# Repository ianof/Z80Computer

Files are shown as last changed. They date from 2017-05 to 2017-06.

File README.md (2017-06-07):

# Z80 Toggle-Switch Computer
A minimalistic computer using the Zilog Z80 microprocessor as an educational display.

The computer will be operated using the following controls:

  * 8 toggle-switches to specify an address in the RAM
  * 8 toggle-switches to enter data into the RAM
  * 8 LEDs to display the address bus
  * 8 LEDs to display the data bus
  * A potentiometer to control the clock speed
  * A toggle-switch to switch between running and writing to the RAM
  * A toggle-switch to switch between running continuously and single-stepping instructions
  * A button to step instructions
  * A button to read from the RAM
  * A button to write to the RAM

The computer will be in a laser-cut plywood housing. SolidWorks files for this can be found in the "Housing" folder.

A printed circuit board contains all the circuitry for the computer. Gerber files for this can be found in the "PCBFiles" folder. A schematic can be found in the "KiCad" folder.

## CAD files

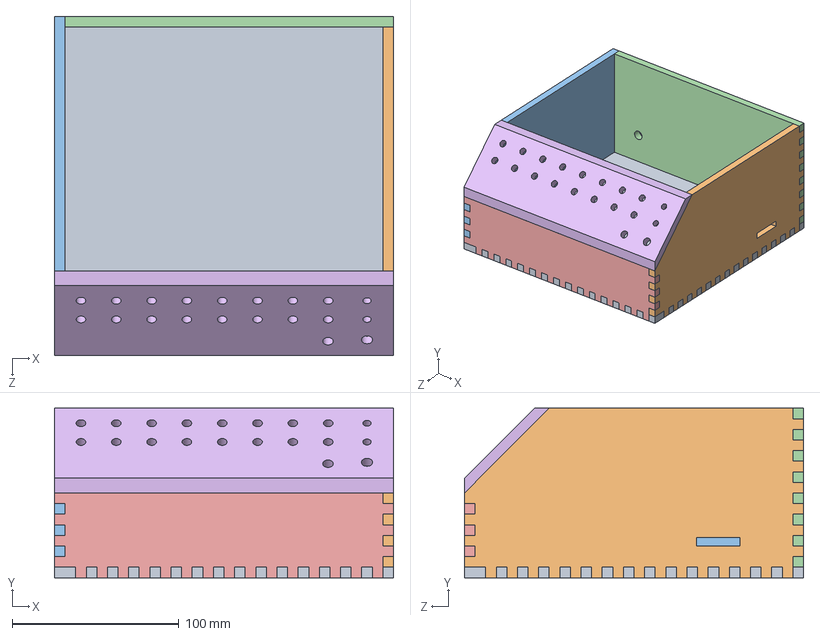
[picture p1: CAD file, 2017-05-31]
Housing/Z80 Box_assembly.SLDASM
203.2 x 101.6 x 203.2 mm
Z80 Box_base
Z80 Box_side_right
Z80 Box_side_left
Z80 Box_back
Z80 Box_front_bottom
Z80 Box_front_top

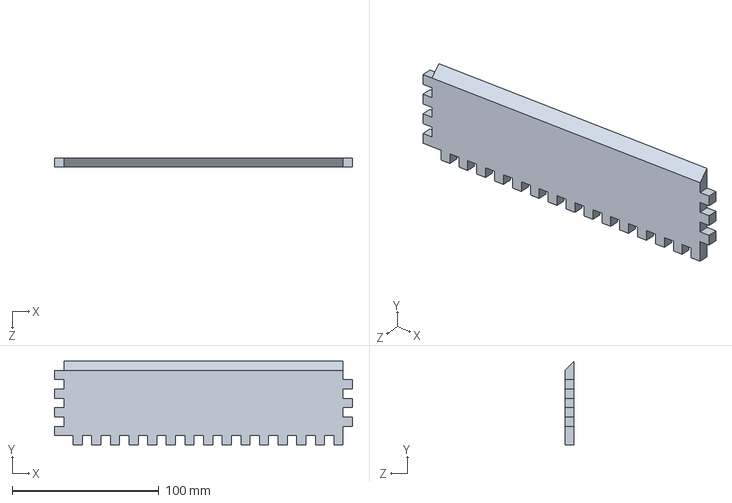
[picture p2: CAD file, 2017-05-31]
Housing/Z80 Box_front_bottom.SLDPRT
203.2 x 57.1 x 6.35 mm

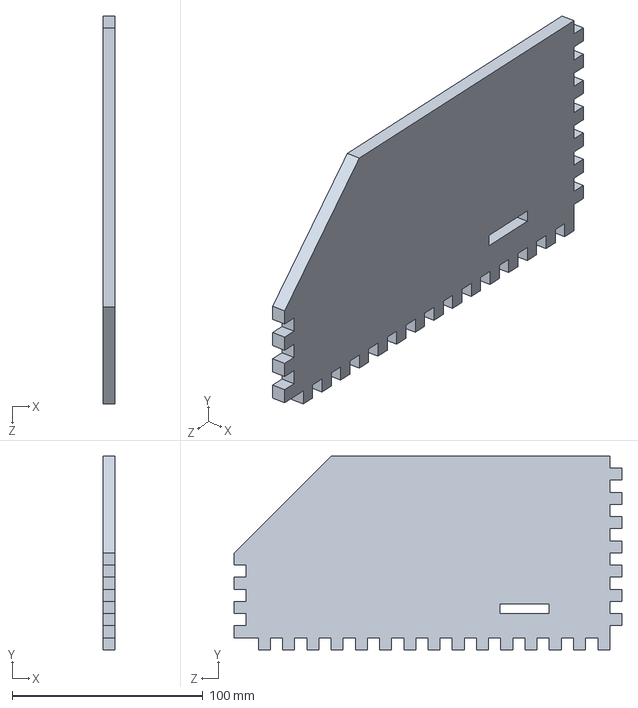
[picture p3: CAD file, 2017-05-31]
Housing/Z80 Box_side_right.SLDPRT
6.35 x 101.6 x 203.2 mm

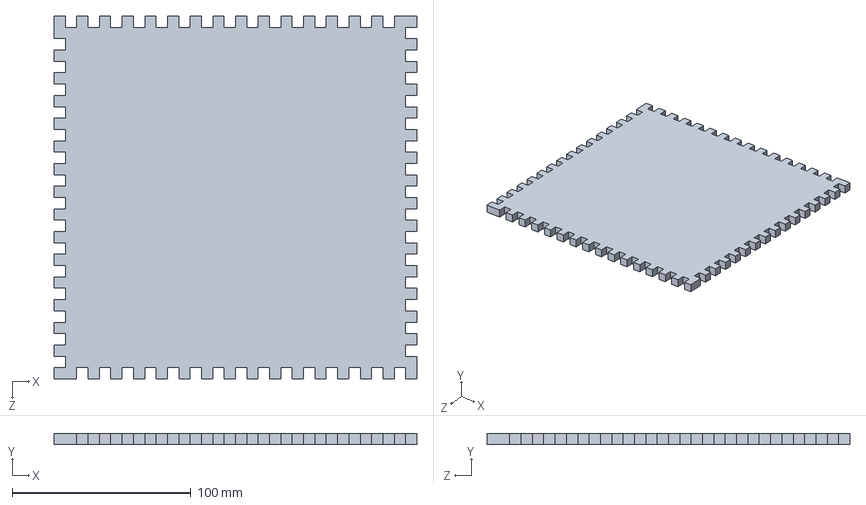
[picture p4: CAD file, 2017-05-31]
Housing/Z80 Box_base.SLDPRT
203.2 x 6.35 x 203.2 mm

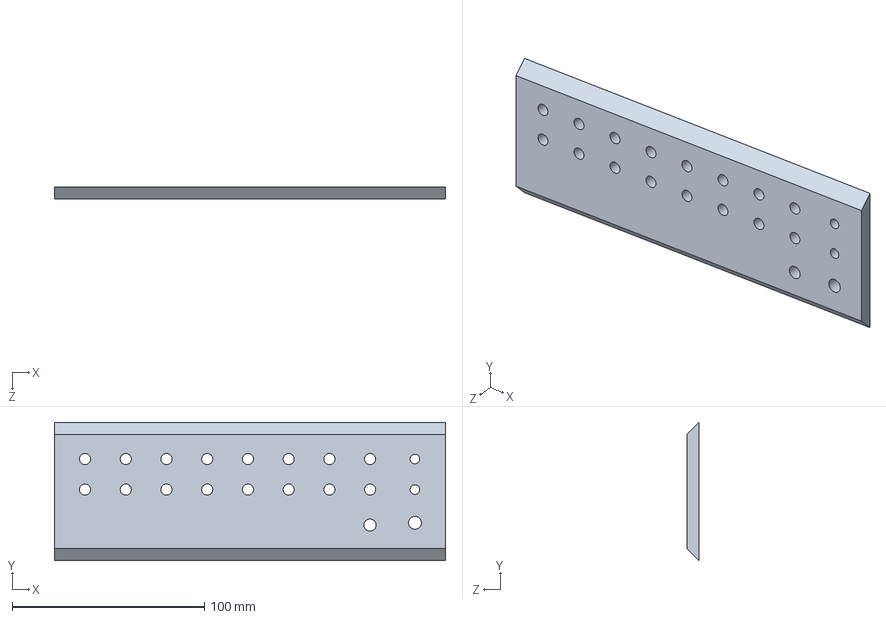
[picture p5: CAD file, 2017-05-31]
Housing/Z80 Box_front_top.SLDPRT
203.2 x 71.8 x 6.35 mm

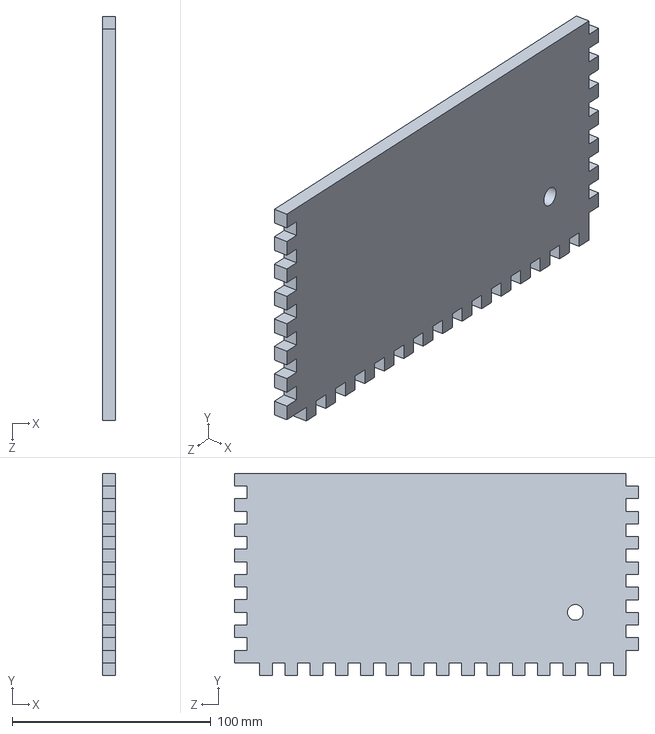
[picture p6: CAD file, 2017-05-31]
Housing/Z80 Box_back.SLDPRT
6.35 x 101.6 x 203.2 mm

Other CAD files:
Housing/Z80 Box_side_left.SLDPRT

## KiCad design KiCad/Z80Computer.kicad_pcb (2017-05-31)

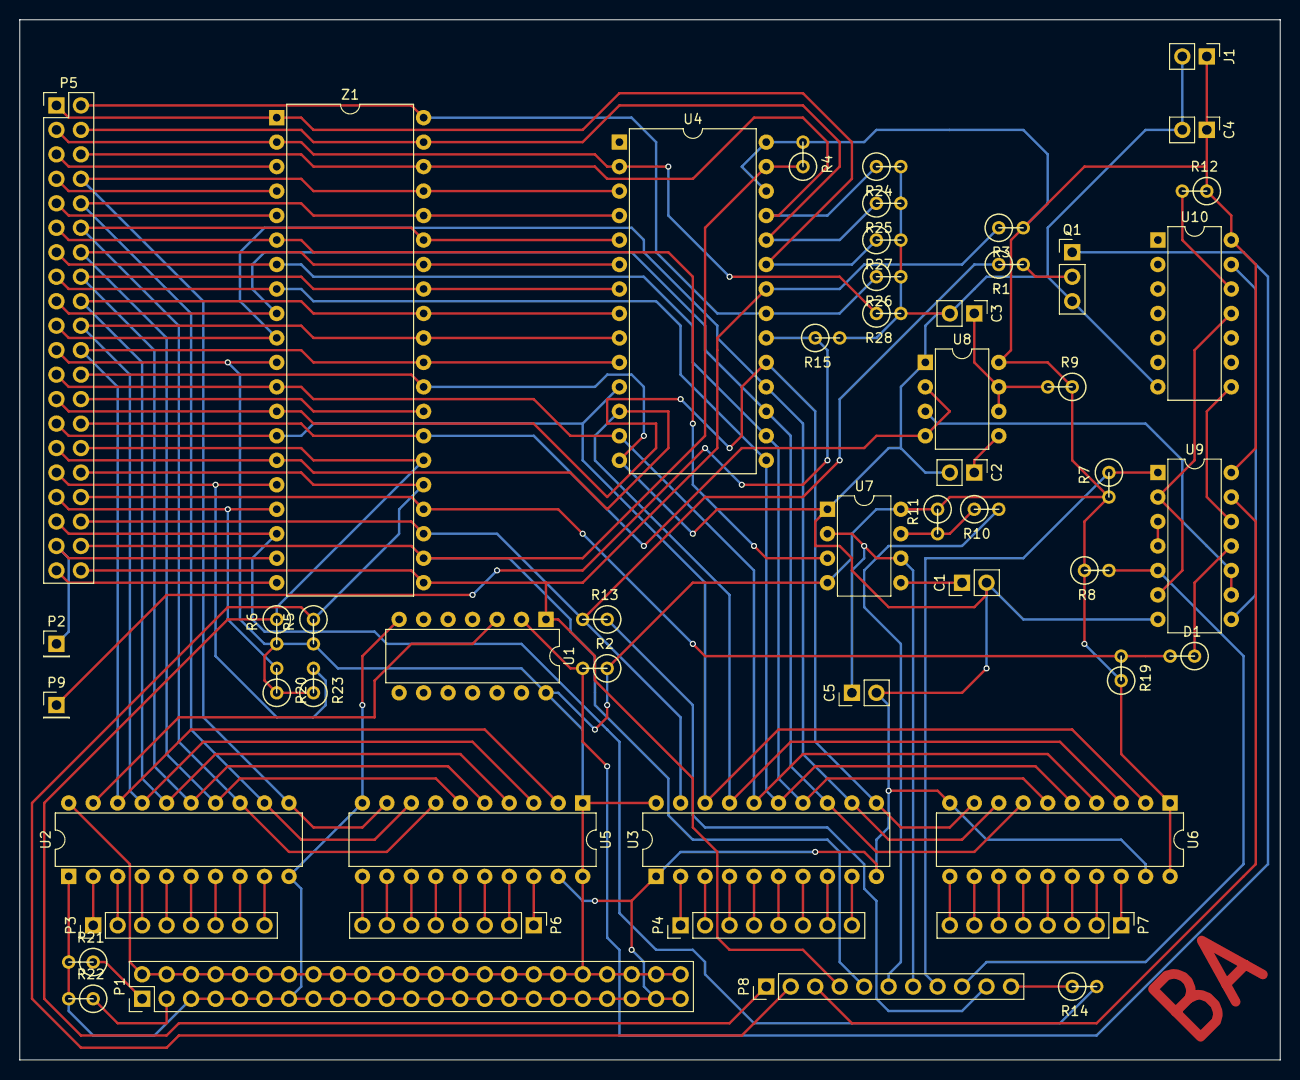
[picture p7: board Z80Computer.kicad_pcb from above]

Board: 2 copper layers, 130.8 x 107.9 mm, 53 parts (0 on the bottom side), 96 nets.

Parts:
C1, C2, C3: 10nF; Pin_Header_Straight_1x02_Pitch2.54mm
C4, C5: 10uF; Pin_Header_Straight_1x02_Pitch2.54mm
D1: D; R1
J1: Screw_Terminal_Power_Input; Pin_Header_Straight_1x02_Pitch2.54mm
P1: CONN_02X23; Pin_Header_Straight_2x23_Pitch2.54mm
P2, P9: CONN_01X01; Pin_Header_Straight_1x01_Pitch2.54mm
P3, P4, P6, P7: CONN_01X08; Pin_Header_Straight_1x08_Pitch2.54mm
P5: CONN_02X20; Pin_Header_Straight_2x20_Pitch2.54mm
P8: CONN_01X11; Pin_Header_Straight_1x11_Pitch2.54mm
Q1: Q_NPN_CBE; Pin_Header_Straight_1x03_Pitch2.54mm
R1: 100k; R1
R2, R3, R4, R5, R6, R7, R8, R9, R11, R12, R15, R19, R20, R23, R24, R25, R26, R27, R28: 10k; R1
R10: 3.3k; R1
R13, R14: 220; R1
R21, R22: 630; R1
U1, U9: 7400; DIP-14_W7.62mm
U2, U3, U5, U6: SN74LVC245A; DIP-20_W7.62mm
U4: AS6C6264; DIP-28_W15.24mm
U7, U8: NE555; DIP-8_W7.62mm
U10: 74LS74; DIP-14_W7.62mm
Z1: Z80; DIP-40_W15.24mm

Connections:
BUSACK: P5.36, R1.1, R13.2, U3.19, Z1.23
BUSRQ: P5.32, P8.2, R5.1, Z1.25
CLK: P5.11, U7.3, Z1.6
GND: C1.2, C2.2, C3.2, C4.2, C5.2, J1.2, P1.5, P1.7, P1.9, P1.11, P1.13, P1.15, P1.17, P1.19, P1.21, P1.23, P1.25, P1.27, P1.29, P1.31, P1.33, P1.35, P1.37, P1.39, P1.41, P1.43, P1.45, P5.24, Q1.3, R15.2, R21.2, R22.2, R24.2, R25.2, R26.2, R27.2, R28.2, U1.7, U2.1, U2.10, U3.1, U3.10, U4.14, U5.10, U5.19, U6.10, U6.19, U7.1, U8.1, U9.7, U10.7, Z1.29
HALT: P5.35, R14.2, Z1.18
INT: P5.31, R23.2, Z1.16
IOREQ: P5.39, Z1.20
M1: P5.28, U8.2, U8.4, Z1.27
MREQ: P2.1, P5.37, Z1.19
NMI: P5.33, R20.2, Z1.17
unnamed: C1.1, U7.5
unnamed: C2.1, U8.5
unnamed: C3.1, R9.2, U8.6, U8.7
unnamed: C5.1, P8.7, U7.2, U7.6
unnamed: D1.1, U9.11
unnamed: P1.1, R21.1
unnamed: P1.3, R22.1
unnamed: P3.1, U2.2
unnamed: P3.2, U2.3
unnamed: P3.3, U2.4
unnamed: P3.4, U2.5
unnamed: P3.5, U2.6
unnamed: P3.6, U2.7
unnamed: P3.7, U2.8
unnamed: P3.8, U2.9
unnamed: P4.1, U3.2
unnamed: P4.2, U3.3
unnamed: P4.3, U3.4
unnamed: P4.4, U3.5
unnamed: P4.5, U3.6
unnamed: P4.6, U3.7
unnamed: P4.7, U3.8
unnamed: P4.8, U3.9
unnamed: P5.1, R27.1, U4.23, Z1.1
unnamed: P5.2, R26.1, U4.21, Z1.40
unnamed: P5.3, R28.1, U4.2, Z1.2
unnamed: P5.4, R25.1, U4.24, Z1.39
unnamed: P5.5, Z1.3
unnamed: P5.6, R24.1, U4.25, Z1.38
unnamed: P5.7, Z1.4
unnamed: P5.8, U2.11, U4.3, U5.9, Z1.37
unnamed: P5.9, Z1.5
unnamed: P5.10, U2.12, U4.4, U5.8, Z1.36
unnamed: P5.12, U2.13, U4.5, U5.7, Z1.35
unnamed: P5.13, U3.14, U4.16, U6.6, Z1.7
unnamed: P5.14, U2.14, U4.6, U5.6, Z1.34
unnamed: P5.15, U3.15, U4.15, U6.5, Z1.8
unnamed: P5.16, U2.15, U4.7, U5.5, Z1.33
unnamed: P5.17, U3.13, U4.17, U6.7, Z1.9
unnamed: P5.18, U2.16, U4.8, U5.4, Z1.32
unnamed: P5.19, U3.12, U4.18, U6.8, Z1.10
unnamed: P5.20, U2.17, U4.9, U5.3, Z1.31
unnamed: P5.22, U2.18, U4.10, U5.2, Z1.30
unnamed: P5.23, U3.16, U4.13, U6.4, Z1.12
unnamed: P5.25, U3.11, U4.19, U6.9, Z1.13
unnamed: P5.27, U3.18, U4.11, U6.2, Z1.14
unnamed: P5.29, U3.17, U4.12, U6.3, Z1.15
unnamed: P6.1, U5.18
unnamed: P6.2, U5.17
unnamed: P6.3, U5.16
unnamed: P6.4, U5.15
unnamed: P6.5, U5.14
unnamed: P6.6, U5.13
unnamed: P6.7, U5.12
unnamed: P6.8, U5.11
unnamed: P7.1, U6.18
unnamed: P7.2, U6.17
unnamed: P7.3, U6.16
unnamed: P7.4, U6.15
unnamed: P7.5, U6.14
unnamed: P7.6, U6.13
unnamed: P7.7, U6.12
unnamed: P7.8, U6.11
unnamed: P8.3, U9.13
unnamed: P8.6, R10.2
unnamed: P8.8, R7.1, U9.1
unnamed: P8.9, R8.2, U9.5
unnamed: P8.10, R13.1
unnamed: P8.11, R14.1
unnamed: P9.1, R15.1, U4.20
unnamed: Q1.1, R2.2, U1.2
unnamed: Q1.2, R1.2
unnamed: R10.1, R11.2, U7.7
unnamed: R12.2, U10.12
unnamed: U1.3, U2.19
unnamed: U8.3, U9.9, U9.10
unnamed: U9.3, U9.4
unnamed: U9.12, U10.8
unnamed: U9.2, U9.6, U10.11
unnamed: U9.8, U10.13
RD: P5.40, P8.4, R3.1, U1.1, U4.22, Z1.21
RESET: P5.30, P8.1, R6.1, Z1.26
RFSH: P5.26, Z1.28
VCC: C4.1, J1.1, P1.2, P1.4, P1.6, P1.8, P1.10, P1.12, P1.14, P1.16, P1.18, P1.20, P1.22, P1.24, P1.26, P1.28, P1.30, P1.32, P1.34, P1.36, P1.38, P1.40, P1.42, P1.44, P1.46, P5.21, R2.1, R3.2, R4.2, R5.2, R6.2, R7.2, R8.1, R9.1, R11.1, R12.1, R19.1, R20.1, R23.1, U1.14, U2.20, U3.20, U4.26, U4.28, U5.1, U5.20, U6.1, U6.20, U7.4, U7.8, U8.8, U9.14, U10.14, Z1.11
WAIT: D1.2, P5.34, R19.2, Z1.24
WR: P5.38, P8.5, R4.1, U4.27, Z1.22

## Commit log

2017-05-31 Added PCB Files
    [Apr14_1.kicad_pcb, Apr15_1.kicad_pcb, Apr19_1_AboutToChangeUnits.kicad_pcb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]
2017-05-31 Added housing files
    [Z80 Box_assembly.SLDASM, Z80 Box_back.SLDPRT, Z80 Box_base.SLDPRT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]
